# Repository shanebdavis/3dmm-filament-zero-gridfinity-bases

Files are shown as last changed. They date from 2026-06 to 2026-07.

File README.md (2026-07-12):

# 3DMM Filament Zero — Gridfinity Bases

**What is the absolute minimum filament — and print time — that still makes a usable
Gridfinity base?** That's the whole point of this project. At this point the answer is,
in truth, *filament approximately zero*: there's no way to remove any more material
without making the base non-functional. Hence the name.

Part of the **3D Modular Madness** collection. Released on MakerWorld:
https://makerworld.com/en/models/1384108-gridfinity-base-fastest-lightest-customizable

## The variants

Three levels of structure, depending on your needs — plus connectable versions of each:

- **Net+** — Doubly flexible, but strong in *tension* — which is mostly what a Gridfinity
  base needs anyway. By far the lightest and fastest print. (`net_light` in the source.)
- **Tape+** — Adds horizontal sliding rigidity while staying flexible. Probably the sweet
  spot if you don't care about looks. (`net_heavy` in the source.)
- **Beam** — If you want it to look nice *and* want the strongest option, go for the beam:
  a traditional-looking solid Gridfinity base, still trimmed to the bone for speed.
  (`rigid` in the source.)
- **Beam+** — Beam, made connectable (see below). Identical to Beam except the *exposed*
  outer-perimeter corners use a special profile designed to mate with neighbouring prints.
  Any perimeter corner on an edge with a drawer spacer falls back to the plain Beam outer
  corner. (`net_rigid` in the source.)

### Connecting plates into one big grid

A natural fallout of how the Net and Tape versions are built: their corners made it
natural to design a **connector** that joins separately-printed plates, so if possible you
can interconnect all your Gridfinity into one large piece. Once the connectors existed,
**Beam+** followed — so the nicest-looking, strongest option can use the connectors too.

## Benchmarks

Bambu Studio slicer estimates on an **A1 mini**, normalized per 42 mm tile (most rows are a
4×4 / 16-tile plate). Lower is better on both columns. ★ = this project.

| Model | By | g / tile | s / tile |
|---|-----|---:|---:|
| ★ **3DMM Net+** | this project | **0.167** | **23.5** |
| Ultralight+ Gridfinity Bases | DBT85 | 0.267 | 52.3 |
| ★ **3DMM Tape+** | this project | 0.326 | 49.9 |
| ★ **3DMM Beam** | this project | 0.500 | 74.4 |
| Lightest Gridfinity Base Ever | Sparky | 0.780 | 96.3 |
| 3DMM Original Ultimate Turbo | this project (old) | 0.828 | 51.9 |
| Gridfinity Lightweight Stackable | DJR Engineering | 1.081 | 123.8 |
| Slim Gridfinity Base (IKEA Alex) | — | 1.258 | 138.9 |
| Gridfinity Simple Base | Schmidsfeld | 1.324 | 243.8 |

Highlights:

- **Net+ is the lightest and fastest base in the field** — 0.167 g/tile, ~37% less filament
  than the next-lightest (Ultralight+) and ~2.2× faster per tile.
- **Beam — a traditional, solid-looking base — beats "Lightest Gridfinity Base Ever"** by
  ~36% on filament and ~23% on time, while still looking like a normal Gridfinity base.
- **Tape+** adds real semi-rigid cross-bracing for only a little more filament than corner-only
  designs, at comparable print speed (49.9 s/tile vs Ultralight+'s 52.3 s/tile).
- Versus a standard Simple Base, **Net+ uses ~1/8th the filament and prints ~10× faster** per tile.

## Repo layout

```
src/               OpenSCAD source — the parametric assembler
stl/               Source geometry: per-variant Corner and Connector STLs
tools/             STL → polyhedron() inliner (regenerates the geometry baked into the .scad)
inline-stls.sh     Convenience wrapper: re-inline the STLs into the .scad
generate.sh        Batch-render the standard sizes for every model type
export_plates.sh   Auto Baseplates: render each plate to its own STL (build/plates/)
make_makerworld.sh Generate the two MakerWorld customizer variants (build-src/)
tools/build_variants.py  The variant builder behind make_makerworld.sh
build-src/         The generated customizer variants, committed so the shipped
                   files exist verbatim even without rerunning the generator
```

`src/gridfinity_base.scad` is **self-contained**: the corner / connector geometry is
inlined directly as `polyhedron()` blocks, so the single file renders anywhere —
including MakerWorld's Parametric Model Maker — with no external STL dependencies. The
`stl/` folder is kept as the editable source of truth, and `tools/inline_stls.py`
regenerates the inlined blocks from it. See *Inlining the geometry* below.

## Installing OpenSCAD

On macOS, install via Homebrew:

```
brew install --cask openscad
```

This installs the OpenSCAD app (and the `openscad` CLI used for headless rendering).

## Customizing your layout (OpenSCAD)

1. Open `src/gridfinity_base.scad` in OpenSCAD.
2. Open the Customizer: **Window → Customizer**.
3. Set:
   - **Model** — Net+, Tape+, Beam+, or Beam
   - **Sparse** — merge cells up to double width/depth and drop the internal walls
     between them: roughly **half the filament and print time** on large areas.
     Corners stay at standard Gridfinity positions (nothing is scaled — only the
     connectors between corners stretch), so bins seat and plates tile exactly as
     usual, just with less support under them. Works per plate in Auto Baseplates
     too; half cells are never merged, and it's ignored when Custom Shape cuts
     are set.
   - **Columns** / **Rows** — grid size in 42 mm cells, in 0.5 steps from 1 to 20.5.
     A `.5` appends a fully-enclosed half-cell (21 mm) column and/or row, for fitting
     odd drawer sizes (e.g. `2.5` = two full cells plus a half)
   - **Custom Shape** — carve a non-rectangular plate by removing squares from the
     left / right end of each row (row 1 = the front row). Corners, connectors and
     drawer spacers all adapt automatically: spacers only run along squares that
     survived the cuts, and each row always keeps at least one square. The Console
     warns if adjacent rows no longer overlap (which would split the plate in two).
   - **Drawer Spacers** — front / back / left / right, in mm (0 = none, 41 mm max).
     Adds a triangular spacer that projects outward from that edge so the plate sits
     flush in a drawer. Each is independent, so you can pad just the sides you need.
     A tie-rail runs along the outer edge of each spaced side, locking the spacers
     together for rigidity. Past 41 mm, add another Gridfinity cell instead.
   - **Auto Baseplates** — fill a whole area with one click: enter the total width
     and depth to cover (both must be non-zero to activate — otherwise everything
     works as normal) and pick your printer (or a custom printable area). Printer
     sizes are the largest single-color rectangle from the official Bambu Studio
     machine profiles, not the advertised bed — e.g. the P1/X1 series lose an
     18×28 mm front-left corner to the filament-cutter stopper (so 238×256 usable,
     with plates placed right of the corner), and the dual-nozzle H2D/H2C print a
     single color from one nozzle, which only reaches 325 mm of the bed. The solver
     fits the largest half-cell grid inside the area, splits it into plates that each
     fit your printer, and converts the leftover millimeters into drawer spacers so
     the assembled footprint is *exactly* what you entered. While active it overrides
     Grid, Drawer Spacers and Custom Shape. **Width alignment** (left / center /
     right / none) and **Depth alignment** (front / center / back / none) pick which
     side of the drawer the grid hugs — the spacers fill the opposite side(s), and
     "none" drops them so the set shrinks to the bare grid on that axis. **Half
     tiles** (uncheck for whole 42 mm squares only; the extra leftover goes to the
     spacers). The preview shows all plates laid out in their assembled
     positions with a small gap. With **Beam+**, plate-to-plate edges get the
     interlocking corners automatically, so the finished grid clips together.
     The Console lists every plate size and its printed footprint.

     To print, export the whole layout as **one STL**, import it into the slicer,
     then **Split to Objects** and auto-arrange (press **A** in Bambu Studio) —
     every plate separates cleanly into its own object (see *cavity vents* in the
     MakerWorld section). To render each plate to its own file instead, run

     ```
     ./export_plates.sh -D cover_width=500 -D cover_depth=450 -D 'printer="p1s"'
     ```

     which renders every plate in parallel to `build/plates/… - Plate NN.stl`
     (driving the hidden `export_plate` parameter via `-D`). Plates are numbered
     left to right, then front to back.
   - **Advanced** — pitch (42 mm = standard Gridfinity), centering, and preview colour
4. `F5` to preview, `F6` to render, then **File → Export → Export as STL**.

The **Console** (**View → Console**) prints the total outer footprint in mm
(`Total size: … wide (X) x … deep (Y)`), including any spacers, so you can check it
against your drawer before exporting.

## Publishing on MakerWorld (two customizers)

MakerWorld gets **two purpose-built customizer scripts**, both generated from
the one source file:

```
./make_makerworld.sh
# -> build-src/3DMM Filament Zero Gridfinity Single Baseplate.scad   (Single-Plate)
# -> build-src/3DMM Filament Zero Gridfinity Multi Baseplate.scad    (Multi-Plate)
```

MakerWorld auto-expands only the *first* parameter group, so each variant leads
with a **Basic** group holding everything a user normally touches:

- **Single-Plate**: Basic (model, grid size, sparse, drawer spacers), then
  Custom Shape and Advanced — the classic one-plate customizer, with the Auto
  Baseplates solver pinned off.
- **Multi-Plate**: Basic (model, printer, area to cover, fill toggles, sparse),
  then Advanced. The manual Grid / Drawer Spacers / Custom Shape settings are
  pinned off, and it ships with a 400×400 mm cover area so the first preview
  shows a real layout.

Both are plain single-output scripts — deliberately **no Parametric Model
Maker multi-plate hooks** — so MakerWorld keeps the **STL download** button on
both listings. STL is the point: PMM's multi-plate 3MF ships MakerWorld's
default print profile, which is wrong for these models, and walking makers
through exporting objects out of it into a correct profile was tedious. With
an STL the maker starts inside our published print profile and stays there.
Printing a Baseplate Set is three inputs in Bambu Studio: import the STL into
the print profile, click it and **Split to Objects**, press **A** to
auto-arrange. Done.

Each variant is the source file with only the Customizer parameter header
rearranged — parameters of omitted sections are pinned to their defaults in a
hidden block, and everything below the header is emitted byte-identical.
`tools/build_variants.py` fails the build if an expected section or parameter
disappears, so the variants can't silently drift from
`src/gridfinity_base.scad` (which remains the full-capability script for local
development). MakerWorld names the downloaded file after the uploaded `.scad`,
so the build outputs carry the product names — rename them in
`tools/build_variants.py` if the product names change.

### Cavity vents (why Split to Objects works)

The Beam/Beam+ corners intentionally enclose sealed air pockets at interior
cell crossings — they split the doubled walls into separated perimeter lines
when sliced. A sealed cavity is always a separate shell in an exported mesh,
so slicers' *Split to Objects* used to break those pockets out as dozens of
loose boxes (and silently delete the inner structure from the plate). Every
pocket is therefore vented to the plate's underside through a hair-thin
channel (`crossing_vents()` in the source): the mesh becomes one connected
shell per plate, the pockets survive splitting, and the channels are far below
one extrusion width so they never appear in toolpaths.

## References & inspiration

These makers did excellent work, and their designs directly inspired this project. They
raised the bar — this project is my attempt to push it further. Go give them a boost.

- **[Ultralight+ Gridfinity Bases](https://makerworld.com/en/models/1226917-ultralight-gridfinity-bases)**
  by DBT85 — Corner-only alignment bases (the grid sides are skipped entirely, since only
  the corners are needed to align bins), with optional pins to connect plates. Roughly
  6.5 g and ~20 min for a 2-wall 5×5 on a P1S. The closest reference point for the
  **Net+** and **Tape+** variants.
- **[Lightest Gridfinity Base Ever – Customizable](https://makerworld.com/en/models/1685835-lightest-gridfinity-base-ever-customizable)**
  by Sparky — Parametric, skeletonized walls-only base with the bottom lip and inter-grid
  overhangs removed; a 4×4 in ~14 min on a 0.8 mm nozzle (1 wall). The reference point for
  the **Beam** variant.
- **[Gridfinity Lightweight Stackable Base Plates](https://makerworld.com/en/models/1927235-gridfinity-lightweight-stackable-base-plates)**
  by DJR Engineering — A clever stackable "peanut" interlock so you can run a whole
  Z-height stack overnight. It requires support material (an AMS) to separate the stacked
  layers. A genuinely interesting idea — but in practice the support material and per-plate
  overhead mean it isn't a net win on time or filament versus printing flat.
- **[Gridfinity Simple Base – all sizes](https://makerworld.com/en/models/700948-gridfinity-simple-base-all-sizes)**
  by Schmidsfeld — The popular, standard full baseplate (built with the FreeCAD Gridfinity
  Workbench). The non-optimized baseline for "normal" Gridfinity weight and print time.

Gridfinity itself was created by Zack Freeman as an open, free system — a framework for the
community.

## How it works

The base is assembled from two reused source parts per variant — a **corner** and a
**connector** beam. `src/gridfinity_base.scad` places four corners per 42 mm cell and
joins them with connector beams, then tiles that cell across your chosen grid. Because
every cell reuses the same inlined geometry, file size and slicing stay tiny even on
large plates.

## Inlining the geometry (and the STL winding gotcha)

The corner and connector parts are modeled by hand (in Shapr3D) and live in `stl/` as
small binary STL meshes. Rather than have the `.scad` `import()` them at render time —
which needs the files alongside the script and is **not supported by MakerWorld's
Parametric Model Maker** — the geometry is **inlined** into `src/gridfinity_base.scad`
as `polyhedron()` blocks. That makes the script a single self-contained file that runs
anywhere.

The mapping lives in the source itself: each inlined module is preceded by a directive
comment naming its STL, e.g.

```
// source-stl: AT Net Rigid Outer Corner.stl (normalize)
module mesh_corner_net_rigid_outer() {
  polyhedron( ... );
}
```

Running `./inline-stls.sh` (a thin wrapper around `tools/inline_stls.py`) scans those
directives, reads each named STL from `stl/`, converts it, and rewrites that module in
place — so after editing a mesh you just re-export the STL and run the script. It can be
run from anywhere; `(normalize)` shifts a corner mesh so its outer corner lands at the
origin.

For a tight edit loop, run `./inline-stls.sh --watch`: it stays running and re-inlines
automatically whenever any `stl/*.stl` changes, so re-exporting from your modeller is
enough to refresh the `.scad` (it only rewrites the file when the geometry actually
changes). Ctrl-C to stop.

Per mesh, the conversion (binary STL → `polyhedron()`) is:

1. **Parse** the binary STL triangles.
2. **Weld** duplicate vertices (round to 4 dp, dedupe) into a points + faces list, so the
   result is a clean manifold rather than triangle soup.
3. **Normalize** corner meshes so the outer corner sits at the origin in the +X +Y
   quadrant (the script then just rotates and places them).
4. **Reverse the face winding** — see below.
5. Emit `polyhedron(points=…, faces=…, convexity=6)`.

### The winding gotcha

STL and OpenSCAD disagree on how a triangle's vertices are ordered:

- **STL** orders them **counter-clockwise as seen from outside** (the outward normal by
  the right-hand rule).
- **OpenSCAD `polyhedron()`** wants them **clockwise from outside**.

So copying STL triangles straight into `polyhedron()` produces **inverted, inside-out
normals**. This is easy to miss because it depends on the rendering backend:

- **CGAL** (older OpenSCAD, e.g. the 2021 macOS build) re-orients faces by topology, so it
  silently fixes the inversion — everything looks fine locally.
- **Manifold** (newer OpenSCAD, and what **MakerWorld** uses) trusts the supplied winding,
  so the inverted faces render inside-out.

That's exactly the bug we hit: the corners and the beam connector (both `polyhedron()`)
showed inside-out on MakerWorld while the native `cube()` connectors were fine, and the
local Mac app looked correct either way. The fix is to **reverse every face**
(`[a,b,c] → [a,c,b]`) during conversion. `tools/inline_stls.py` does this robustly: it
computes each mesh's signed volume and flips the winding whenever the source comes in
counter-clockwise, so the result is correct regardless of how the STL was exported.

## License

MIT — see [LICENSE](LICENSE).

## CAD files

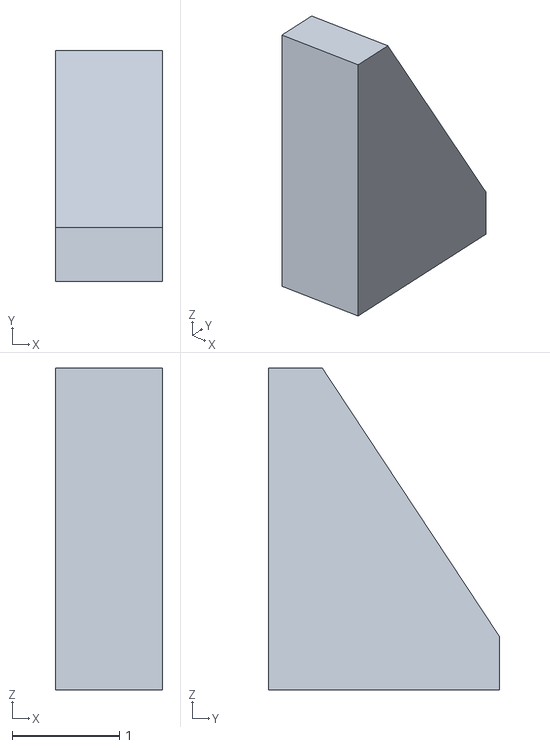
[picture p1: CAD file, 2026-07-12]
stl/AT Extension V2 End.stl
1.00 x 2.15 x 3.00

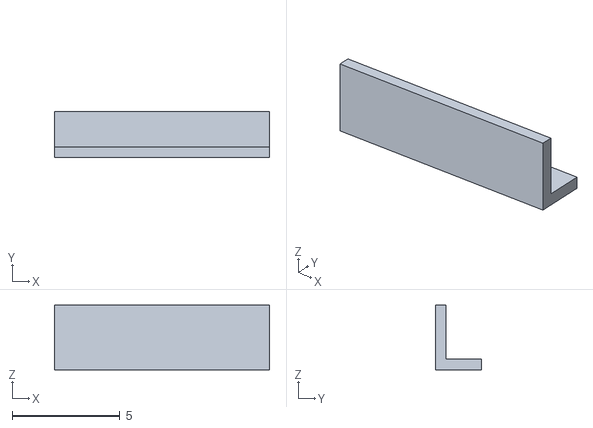
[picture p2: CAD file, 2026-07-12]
stl/AT Extension V2 Extender.stl
10.0 x 2.15 x 3.00

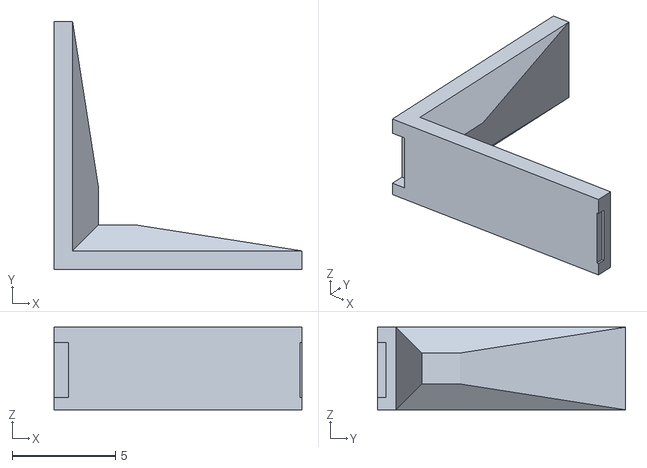
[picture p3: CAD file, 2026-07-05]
stl/AT Rigid Inner Corner.stl
12.0 x 12.0 x 4.00

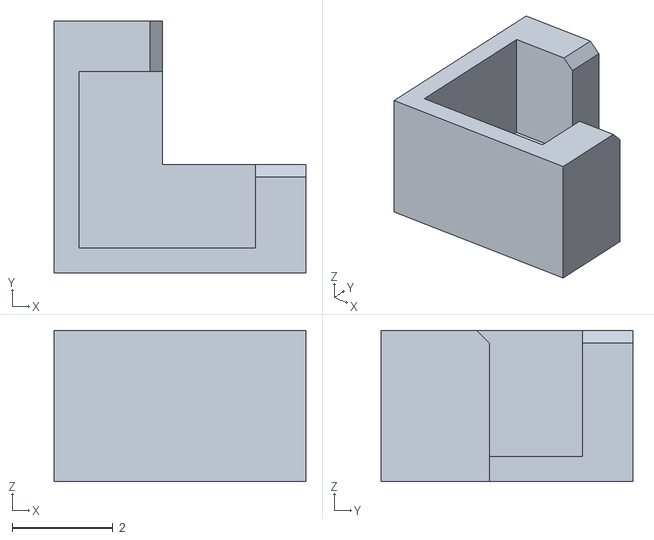
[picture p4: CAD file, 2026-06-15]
stl/AT Net Heavy Corner.stl
5.00 x 5.00 x 3.00

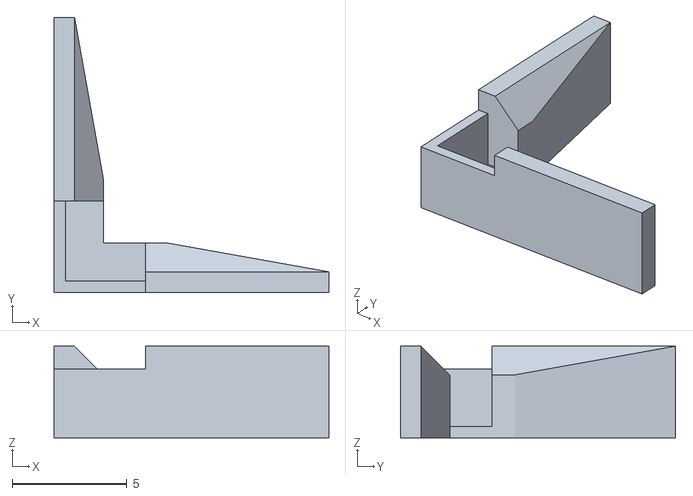
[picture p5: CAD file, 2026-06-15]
stl/AT Net Rigid InnerOuter Corner.stl
12.0 x 12.0 x 4.00

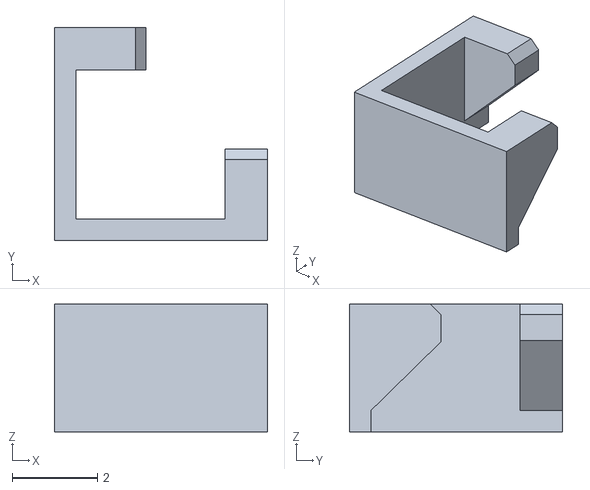
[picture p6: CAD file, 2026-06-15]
stl/AT Net Light Corner.stl
5.00 x 5.00 x 3.00

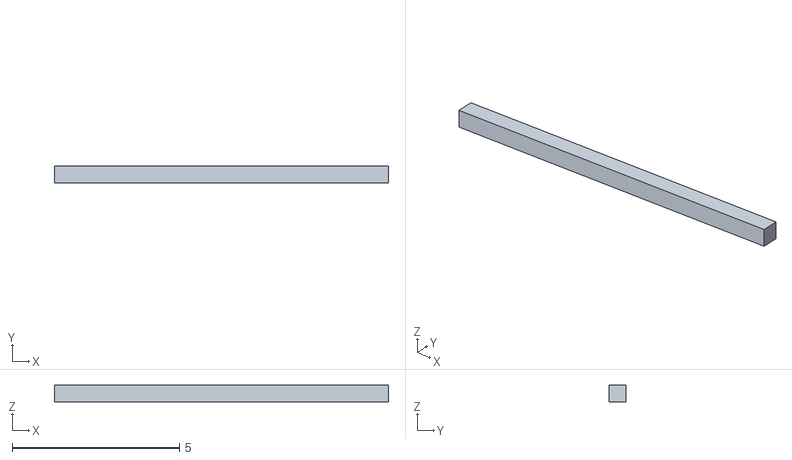
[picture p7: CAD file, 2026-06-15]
stl/AT Net Light Connector.stl
10.0 x 0.5 x 0.5

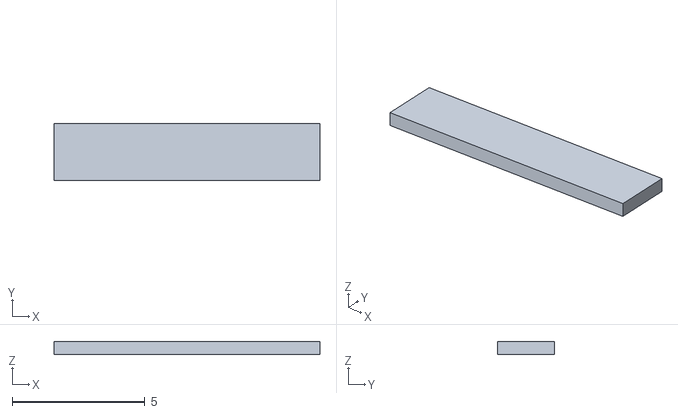
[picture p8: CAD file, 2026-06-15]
stl/AT Net Heavy Connector.stl
10.0 x 2.15 x 0.5

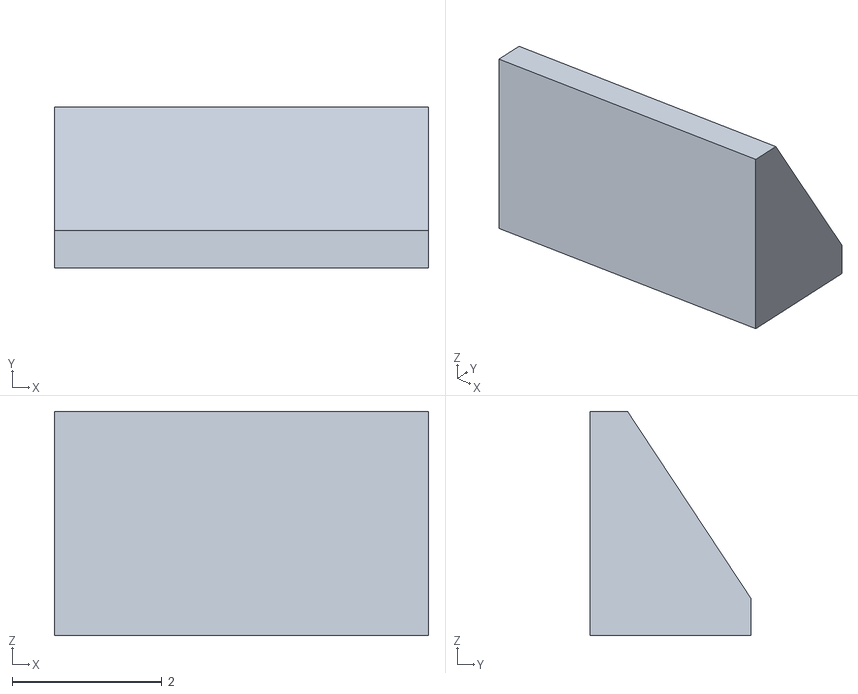
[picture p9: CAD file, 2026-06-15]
stl/AT Extension.stl
5.00 x 2.15 x 3.00

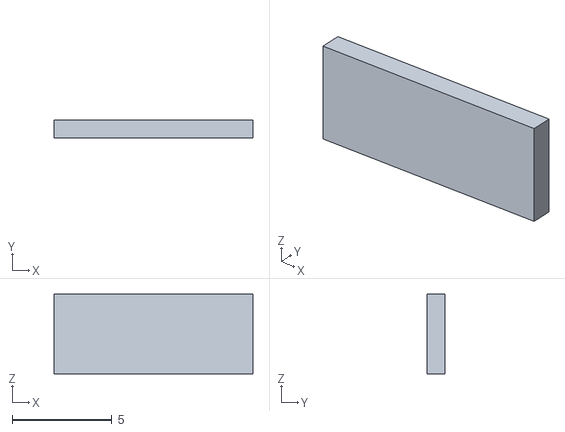
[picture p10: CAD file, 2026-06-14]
stl/AT Net Rigid Connector.stl
10.0 x 0.9 x 4.00

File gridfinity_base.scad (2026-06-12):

// ============================================================
//  AT Ultra-Light Gridfinity Base  —  parametric assembler
// ============================================================
//  Keep this .scad file in the SAME folder as the corner STLs,
//  because import() uses relative paths.
//
//  Open in OpenSCAD, then: Window menu -> Customizer to get the
//  dropdown + sliders below. F5 = preview, F6 = render, then
//  File -> Export -> Export as STL.
// ============================================================

/* [Model] */
// Which base style to build
model = "net_light"; // [net_light:Net Light, net_heavy:Net Heavy, rigid:Solid (Rigid)]

/* [Grid] */
// Squares wide
columns = 2; // [1:1:20]
// Squares tall
rows = 2;    // [1:1:20]

/* [Advanced] */
// Grid spacing in mm (42 = standard gridfinity)
pitch = 42;      // [21:1:84]
// Smoothness of any curves
$fn = 48;

// ---- end of Customizer parameters --------------------------

// Per-model lookup. The "offset" is where each STL currently sits
// in space (Shapr3D laid them out side by side); we subtract it so
// every corner's OUTER corner lands at the origin (0,0).
corner_file =
    model == "net_light" ? "AT Net Light Corner.stl" :
    model == "net_heavy" ? "AT Net Heavy Corner.stl" :
                           "AT Rigid Corner.stl";

corner_offset =
    model == "net_light" ? [250, 200, 0] :
    model == "net_heavy" ? [300, 200, 0] :
                           [350, 200, 0];

// Corner footprint along an edge (mm)
corner_size = (model == "rigid") ? 12 : 5;

// Connector cross-section: width (across the edge) x height (up)
conn_w = model == "net_light" ? 0.5 :
         model == "net_heavy" ? 2.15 :
                                0.9;   // rigid
conn_h = (model == "rigid") ? 4.0 : 0.5;

// ------------------------------------------------------------
// One imported corner, normalized so its outer corner is at origin
// and it occupies the +X +Y quadrant (profile faces toward center).
module corner_part() {
    translate([-corner_offset[0], -corner_offset[1], -corner_offset[2]])
        import(corner_file);
}

// A connector beam running along +X, flush to the outer edge
// (y: 0..conn_w) and sitting on the bed (z: 0..conn_h).
module connector(len) {
    cube([len, conn_w, conn_h]);
}

// One 42mm (pitch) cell: 4 corners + 4 edge connectors.
// We place the bottom-left corner and its bottom-edge connector,
// then rotate that whole pair 0/90/180/270 about the cell center
// to fill the other three corners and edges.
module cell() {
    gap = pitch - 2 * corner_size;   // length of each connector
    for (a = [0, 90, 180, 270])
        translate([pitch/2, pitch/2, 0])
            rotate([0, 0, a])
                translate([-pitch/2, -pitch/2, 0]) {
                    corner_part();
                    // Butt-joined exactly against the corners — no overlap,
                    // geometry untouched. Coincident faces union cleanly.
                    translate([corner_size, 0, 0])
                        connector(gap);
                }
}

// Tile the cell across the requested grid.
module grid() {
    for (i = [0 : columns - 1], j = [0 : rows - 1])
        translate([i * pitch, j * pitch, 0])
            cell();
}

grid();

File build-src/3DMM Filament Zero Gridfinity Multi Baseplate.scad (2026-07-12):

// ============================================================
//  GENERATED FILE - do not edit. Built by tools/build_variants.py
//  (./make_makerworld.sh) from src/gridfinity_base.scad.
//  Variant: Multi-Plate customizer
// ============================================================

// ============================================================
//  AT Ultra-Light Gridfinity Base  —  parametric assembler
// ============================================================
//  Self-contained: all geometry is inlined as polyhedron() below, so
//  this single file runs anywhere (incl. MakerWorld's Parametric Model
//  Maker / customizer) with no external STL dependencies.
//
//  Open in OpenSCAD, then: Window menu -> Customizer to get the
//  dropdown + sliders below. F5 = preview, F6 = render, then
//  File -> Export -> Export as STL.
// ============================================================

/* [Basic] */
// Which base style to build
model = "net_rigid"; // [net_light:Net+, net_heavy:Tape+, rigid:Beam, net_rigid:Beam+]

// Cover a whole area (a drawer, a shelf) with auto-sized plates: pick your printer,
// set BOTH cover sizes non-zero, and the solver fills the area with the largest grid
// that fits, splits it into plates sized for your printer, and turns the leftover
// millimeters into edge spacers so the assembled footprint is exactly what you asked
// for. While active, the manual Grid, Drawer Spacers and Custom Shape settings are
// ignored.
// Printer the plates must fit on. Sizes are the largest single-color rectangle from the
// official Bambu Studio machine profiles, not the advertised bed: P1/X1 series lose an
// 18x28mm front-left corner to the filament-cutter stopper (plates print full-depth,
// nudged right of the corner), and the dual-nozzle H2/X2 machines are limited to one
// nozzle's reach for a single color.
printer = "p1s"; // [a1_mini:A1 mini (180x180), a1:A1 / P2S / X2D (256x256), p1s:P1P / P1S / X1C / X1E (238x256 - cutter corner), a2l:A2L (330x320), h2s:H2S (340x320), h2d:H2D / H2D Pro / H2C (325x320 single color), custom:Custom (set size under Advanced)]
// Total width (mm) of the area to cover. 0 = off.
cover_width = 400; // [0:1:2000]
// Total depth (front-to-back, mm) of the area to cover. 0 = off.
cover_depth = 400; // [0:1:2000]
// Where the grid sits inside the covered width: drawer spacers fill the leftover millimeters on the other side(s), so the assembled footprint is exactly the cover width. None = no width spacers (the set shrinks to the grid).
width_align = "center"; // [left:Left, center:Center, right:Right, none:None]
// Where the grid sits inside the covered depth. None = no depth spacers.
depth_align = "front"; // [front:Front, center:Center, back:Back, none:None]
// Use a trailing half-size (21mm) column/row when it fits the cover size better. Uncheck for whole 42mm squares only - the leftover goes to the drawer spacers instead.
half_tiles = false;

// Sparse: halves your filament cost by removing internal geometry, while staying fully Gridfinity compatible. Ideal for larger layouts with larger trays.
sparse = false;

/* [Advanced] */
// Center on the plate
centered = true;
// Grid spacing in mm (42: standard gridfinity, 84: double, 168: quad)
pitch = 42;      // [21:1:168]

// Auto Baseplates only: gap between plates in the preview/export, so the slicer's Split to Objects cleanly separates them
tile_gap = 5; // [2:0.5:20]

// Auto Baseplates, Printer = Custom only: printable width (mm)
custom_print_width = 256; // [100:1:1000]
// Auto Baseplates, Printer = Custom only: printable depth (mm)
custom_print_depth = 256; // [100:1:1000]

// Customize the preview color to match your filament. Use standard HTML color codes: e.g. #ff0000 for red. This does not affect the model output.
preview_color = "#0099ff";

/* [Hidden] */
// Fixed in this variant - not part of this customizer's UI.
columns = 4; // [1:0.5:10]
rows = 4;    // [1:0.5:10]
spacer_front = 0; // [0:0.5:41]
spacer_left  = 0; // [0:0.5:41]
spacer_back  = 0; // [0:0.5:41]
spacer_right = 0; // [0:0.5:41]
row_1_left = 0; // [0:1:9]
row_1_right = 0; // [0:1:9]
row_2_left = 0; // [0:1:9]
row_2_right = 0; // [0:1:9]
row_3_left = 0; // [0:1:9]
row_3_right = 0; // [0:1:9]
row_4_left = 0; // [0:1:9]
row_4_right = 0; // [0:1:9]
row_5_left = 0; // [0:1:9]
row_5_right = 0; // [0:1:9]
row_6_left = 0; // [0:1:9]
row_6_right = 0; // [0:1:9]
row_7_left = 0; // [0:1:9]
row_7_right = 0; // [0:1:9]
row_8_left = 0; // [0:1:9]
row_8_right = 0; // [0:1:9]
row_9_left = 0; // [0:1:9]
row_9_right = 0; // [0:1:9]
row_10_left = 0; // [0:1:9]
row_10_right = 0; // [0:1:9]

// ---- end of Customizer parameters --------------------------
// Everything below is internal. The [Hidden] group keeps these
// constants (beam_len, ext_base_len, rail_*, etc.) out of the
// OpenSCAD / MakerWorld Customizer UI.
/* [Hidden] */

// Auto Baseplates only: render a single plate by number (1 = front-left plate,
// counting left to right then front to back) instead of the whole layout. A
// scripting hook for export_plates.sh (openscad -D export_plate=N); 0 = the
// whole layout.
export_plate = 0; // [0:1:36]

// Corner footprint along an edge (mm). Solid and Solid+ share the 12mm corner.
corner_size = (model == "rigid" || model == "net_rigid") ? 12 : 5;

// Connector cross-section: width (across the edge) x height (up). Solid+ (net_rigid)
// uses the same 0.9 x 4.0 connector as Solid (rigid) — it looks just like Solid; only
// its outer-perimeter corners differ (see corner_part).
conn_w = model == "net_light" ? 0.5 :
         model == "net_heavy" ? 2.15 :
                                0.9;   // rigid + net_rigid
conn_h = (model == "rigid" || model == "net_rigid") ? 4.0 : 0.5;

// ------------------------------------------------------------
// One corner, already normalized (outer corner at the origin, in the +X +Y quadrant
// with the profile facing the cell centre). Solid (rigid) and Solid+ (net_rigid)
// distinguish corner roles by how many of the corner's two edges lie on the plate
// boundary:
//   both edges on boundary  -> `outer` corner (a true plate corner)
//   one edge on boundary    -> `innerouter` corner (sits mid-edge: one side is the
//                              perimeter wall, the other mates with the neighbouring cell)
//   neither edge on boundary -> `inner` corner (fully interior, where four cells meet)
// `outer` is true whenever at least one edge is on the boundary; `both` narrows that to a
// true plate corner. Solid+ adds the `plus` role: where any on-boundary edge is *exposed*
// (no drawer spacer) it mates with a neighbouring print, so it swaps in the special Solid+
// outer/innerouter mesh. Only when every boundary edge at the corner is spacered (extenders
// run in each boundary direction) does it fall back to the plain Solid corner.
//
// The InnerOuter mesh is asymmetric — its outer (perimeter) edge runs along local +X and
// its inner (mating) edge along local +Y. rcell places every corner so local +X points at
// that corner's "canonical" boundary side; when the actual boundary edge is the *other*
// one, `swap` mirrors the mesh across its diagonal (swap X/Y) to put the perimeter wall on
// the right edge. `open` marks a corner whose two adjacent squares are present but whose
// diagonal square was removed by a Custom Shape cut (a re-entrant plate corner). Solid+
// must NOT use the fully-interior corner there: its edge-connector clip only fits an
// intersection where every square-corner presents the connectable outer profile, so any
// missing square at the intersection forces the outer piece on all corners around it.
// Plain Solid has no clip and keeps the interior corner. `plus`/`outer`/`both`/`swap`/
// `open` are supplied by rcell; the flexible-net models ignore them all.
module corner_part(plus = true, outer = true, both = true, swap = false, open = false) {
    if      (model == "net_light")                        mesh_corner_net_light();
    else if (model == "net_heavy" || model == "net_beam") mesh_corner_net_heavy();
    else if (model == "net_rigid") {
        if      (plus && both)  mesh_corner_net_rigid_outer();
        else if (plus)          diag(swap) mesh_corner_net_rigid_innerouter();
        else if (outer && both) mesh_corner_rigid_outer();
        else if (outer)         diag(swap) mesh_corner_rigid_innerouter();
        else if (open)          mesh_corner_net_rigid_outer();
        else                    mesh_corner_rigid_inner();
    }
    else {  // rigid / Solid
        if      (outer && both) mesh_corner_rigid_outer();
        else if (outer)         diag(swap) mesh_corner_rigid_innerouter();
        else                    mesh_corner_rigid_inner();
    }
}
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

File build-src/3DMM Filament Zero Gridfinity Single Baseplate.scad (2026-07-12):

// ============================================================
//  GENERATED FILE - do not edit. Built by tools/build_variants.py
//  (./make_makerworld.sh) from src/gridfinity_base.scad.
//  Variant: Single-Plate customizer
// ============================================================

// ============================================================
//  AT Ultra-Light Gridfinity Base  —  parametric assembler
// ============================================================
//  Self-contained: all geometry is inlined as polyhedron() below, so
//  this single file runs anywhere (incl. MakerWorld's Parametric Model
//  Maker / customizer) with no external STL dependencies.
//
//  Open in OpenSCAD, then: Window menu -> Customizer to get the
//  dropdown + sliders below. F5 = preview, F6 = render, then
//  File -> Export -> Export as STL.
// ============================================================

/* [Basic] */
// Which base style to build
model = "rigid"; // [net_light:Net+, net_heavy:Tape+, rigid:Beam, net_rigid:Beam+]

// Squares wide
columns = 4; // [1:0.5:10]
// Squares deep
rows = 4;    // [1:0.5:10]

// Sparse: halves your filament cost by removing internal geometry, while staying fully Gridfinity compatible. Ideal for larger layouts with larger trays.
sparse = false;

// Outward spacer on each side (mm) so the plate sits flush in a drawer. 0 = none.
// Capped at 41 mm — past that, just add another Gridfinity cell instead.
// Front Spacer (mm)
spacer_front = 0; // [0:0.5:41]
// Left Spacer (mm)
spacer_left  = 0; // [0:0.5:41]
// Back Spacer (mm)
spacer_back  = 0; // [0:0.5:41]
// Right Spacer (mm)
spacer_right = 0; // [0:0.5:41]

/* [Custom Shape] */
// Remove squares from row 1 left
row_1_left = 0; // [0:1:9]
// Remove squares from row 1 right
row_1_right = 0; // [0:1:9]
// Remove squares from row 2 left
row_2_left = 0; // [0:1:9]
// Remove squares from row 2 right
row_2_right = 0; // [0:1:9]
// Remove squares from row 3 left
row_3_left = 0; // [0:1:9]
// Remove squares from row 3 right
row_3_right = 0; // [0:1:9]
// Remove squares from row 4 left
row_4_left = 0; // [0:1:9]
// Remove squares from row 4 right
row_4_right = 0; // [0:1:9]
// Remove squares from row 5 left
row_5_left = 0; // [0:1:9]
// Remove squares from row 5 right
row_5_right = 0; // [0:1:9]
// Remove squares from row 6 left
row_6_left = 0; // [0:1:9]
// Remove squares from row 6 right
row_6_right = 0; // [0:1:9]
// Remove squares from row 7 left
row_7_left = 0; // [0:1:9]
// Remove squares from row 7 right
row_7_right = 0; // [0:1:9]
// Remove squares from row 8 left
row_8_left = 0; // [0:1:9]
// Remove squares from row 8 right
row_8_right = 0; // [0:1:9]
// Remove squares from row 9 left
row_9_left = 0; // [0:1:9]
// Remove squares from row 9 right
row_9_right = 0; // [0:1:9]
// Remove squares from row 10 left
row_10_left = 0; // [0:1:9]
// Remove squares from row 10 right
row_10_right = 0; // [0:1:9]

/* [Advanced] */
// Center on the plate
centered = true;
// Grid spacing in mm (42: standard gridfinity, 84: double, 168: quad)
pitch = 42;      // [21:1:168]
// Customize the preview color to match your filament. Use standard HTML color codes: e.g. #ff0000 for red. This does not affect the model output.
preview_color = "#0099ff";

/* [Hidden] */
// Fixed in this variant - not part of this customizer's UI.
printer = "p1s"; // [a1_mini:A1 mini (180x180), a1:A1 / P2S / X2D (256x256), p1s:P1P / P1S / X1C / X1E (238x256 - cutter corner), a2l:A2L (330x320), h2s:H2S (340x320), h2d:H2D / H2D Pro / H2C (325x320 single color), custom:Custom (set size under Advanced)]
cover_width = 0; // [0:1:2000]
cover_depth = 0; // [0:1:2000]
width_align = "center"; // [left:Left, center:Center, right:Right, none:None]
depth_align = "front"; // [front:Front, center:Center, back:Back, none:None]
half_tiles = true;
tile_gap = 5; // [2:0.5:20]
custom_print_width = 256; // [100:1:1000]
custom_print_depth = 256; // [100:1:1000]

// ---- end of Customizer parameters --------------------------
// Everything below is internal. The [Hidden] group keeps these
// constants (beam_len, ext_base_len, rail_*, etc.) out of the
// OpenSCAD / MakerWorld Customizer UI.
/* [Hidden] */

// Auto Baseplates only: render a single plate by number (1 = front-left plate,
// counting left to right then front to back) instead of the whole layout. A
// scripting hook for export_plates.sh (openscad -D export_plate=N); 0 = the
// whole layout.
export_plate = 0; // [0:1:36]

// Corner footprint along an edge (mm). Solid and Solid+ share the 12mm corner.
corner_size = (model == "rigid" || model == "net_rigid") ? 12 : 5;

// Connector cross-section: width (across the edge) x height (up). Solid+ (net_rigid)
// uses the same 0.9 x 4.0 connector as Solid (rigid) — it looks just like Solid; only
// its outer-perimeter corners differ (see corner_part).
conn_w = model == "net_light" ? 0.5 :
         model == "net_heavy" ? 2.15 :
                                0.9;   // rigid + net_rigid
conn_h = (model == "rigid" || model == "net_rigid") ? 4.0 : 0.5;

// ------------------------------------------------------------
// One corner, already normalized (outer corner at the origin, in the +X +Y quadrant
// with the profile facing the cell centre). Solid (rigid) and Solid+ (net_rigid)
// distinguish corner roles by how many of the corner's two edges lie on the plate
// boundary:
//   both edges on boundary  -> `outer` corner (a true plate corner)
//   one edge on boundary    -> `innerouter` corner (sits mid-edge: one side is the
//                              perimeter wall, the other mates with the neighbouring cell)
//   neither edge on boundary -> `inner` corner (fully interior, where four cells meet)
// `outer` is true whenever at least one edge is on the boundary; `both` narrows that to a
// true plate corner. Solid+ adds the `plus` role: where any on-boundary edge is *exposed*
// (no drawer spacer) it mates with a neighbouring print, so it swaps in the special Solid+
// outer/innerouter mesh. Only when every boundary edge at the corner is spacered (extenders
// run in each boundary direction) does it fall back to the plain Solid corner.
//
// The InnerOuter mesh is asymmetric — its outer (perimeter) edge runs along local +X and
// its inner (mating) edge along local +Y. rcell places every corner so local +X points at
// that corner's "canonical" boundary side; when the actual boundary edge is the *other*
// one, `swap` mirrors the mesh across its diagonal (swap X/Y) to put the perimeter wall on
// the right edge. `open` marks a corner whose two adjacent squares are present but whose
// diagonal square was removed by a Custom Shape cut (a re-entrant plate corner). Solid+
// must NOT use the fully-interior corner there: its edge-connector clip only fits an
// intersection where every square-corner presents the connectable outer profile, so any
// missing square at the intersection forces the outer piece on all corners around it.
// Plain Solid has no clip and keeps the interior corner. `plus`/`outer`/`both`/`swap`/
// `open` are supplied by rcell; the flexible-net models ignore them all.
module corner_part(plus = true, outer = true, both = true, swap = false, open = false) {
    if      (model == "net_light")                        mesh_corner_net_light();
    else if (model == "net_heavy" || model == "net_beam") mesh_corner_net_heavy();
    else if (model == "net_rigid") {
        if      (plus && both)  mesh_corner_net_rigid_outer();
        else if (plus)          diag(swap) mesh_corner_net_rigid_innerouter();
        else if (outer && both) mesh_corner_rigid_outer();
        else if (outer)         diag(swap) mesh_corner_rigid_innerouter();
        else if (open)          mesh_corner_net_rigid_outer();
        else                    mesh_corner_rigid_inner();
    }
    else {  // rigid / Solid
        if      (outer && both) mesh_corner_rigid_outer();
        else if (outer)         diag(swap) mesh_corner_rigid_innerouter();
        else                    mesh_corner_rigid_inner();
    }
}

// Mirror children across the corner's diagonal (swap X/Y) when `s` is set — used to flip an
// asymmetric InnerOuter corner so its perimeter wall lands on the correct edge.
module diag(s) {
    if (s) multmatrix([[0,1,0,0],[1,0,0,0],[0,0,1,0],[0,0,0,1]]) children();
    else   children();
}
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

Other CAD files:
stl/AT Net Heavy Beam Connector.stl
stl/AT Rigid InnerOuter Corner.stl
stl/AT Rigid Connector.stl
src/gridfinity_base.scad

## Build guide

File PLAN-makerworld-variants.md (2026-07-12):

# Plan: Split MakerWorld Customizers (Single-Plate / Multi-Plate / Dev)

## The actual problem we're solving

MakerWorld's Parametric Model Maker (PMM) can export Auto Baseplates as a proper
multi-plate 3MF, but **we get almost no control over the print settings inside that
3MF**. This model needs heavily customized settings (ultra-light lattice), so the
downloaded 3MF has a bad print profile. Today the workaround is instructing the user
to open the downloaded 3MF, export every object out of it, and re-import them into a
properly configured print-profile 3MF — very tedious. The goal of every strategy below
is to reduce or eliminate that tedium.

Two strategies will be tried in parallel:

- **Strategy A** (this document, specified): restructure into purpose-built customizers
  so each MakerWorld listing is simple and the STL-friendly path stays first-class.
- **Strategy B** (TBD): to be specified next — a different attack on the print-profile
  problem itself.

## Current architecture (research summary)

- **`src/gridfinity_base.scad`** — single self-contained source of truth. Customizer
  sections in order: `[Model]`, `[Grid]`, `[Drawer Spacers]`, `[Custom Shape]`,
  `[Auto Baseplate Set Generation]`, `[Advanced]`, then `[Hidden]` internals, engine
  code, the Auto Baseplates solver, output modules (`assembly_view()`, `plate(k)`),
  a top-level render guarded by `if (!mw_export)`, and the inlined mesh modules.
- **`src/makerworld_hooks.scad`** — 36 `mw_plate_N()` modules + `mw_assembly_view()`.
  Must never coexist with a live top-level render (PMM renders the top level into
  every plate), which is why hooks live in a separate file.
- **`make_makerworld.sh`** — builds the current multi-plate upload variant:
  flips `mw_export = false` → `true` in the combined source, appends the hooks, writes
  `build/3DMM Filament Zero Gridfinity Baseplates.scad`.
- **`export_plates.sh`** — renders each auto plate to its own STL by passing
  `-D export_plate=k`. **Depends on the `export_plate` parameter existing.**
- **`generate.sh`** — batch STL renders of standard sizes from the combined source.
- **`inline-stls.sh` / `tools/inline_stls.py`** — regenerates the inlined
  `polyhedron()` modules inside `src/gridfinity_base.scad` (hardcoded path).
- OpenSCAD semantics that make this plan cheap: top-level variables are declarative
  (single assignment, position doesn't affect resolution), and everything after a
  `/* [Hidden] */` group header is excluded from the Customizer UI. So "removing" a
  parameter from a variant = moving its assignment into a hidden block; all engine
  code compiles unchanged.

## Strategy A: three build outputs from one source

### Source organization: keep the combined file (recommended)

Keep `src/gridfinity_base.scad` as the one source of truth, and add lightweight
**section markers** (comments like `// @section grid`) around the Customizer parameter
blocks. A new build tool assembles variants by transforming only the parameter header
(reorder sections, demote pinned params to a hidden block, flip `mw_export`) and
appending hooks where needed. The engine/solver/mesh code is byte-identical in every
variant.

Why not split into fragment files assembled by concatenation? It was considered
(`params_*.scad` + `core.scad` + `solver.scad` + per-target output files), but:

- The dev iteration cycle gets *worse*: you can no longer just open the src file in
  OpenSCAD and hit F5 — you'd have to rebuild after every edit or develop against a
  build artifact.
- `tools/inline_stls.py` and both shell scripts would need repointing.
- Cross-section references (e.g. `assembly_view()` touches manual *and* auto params)
  force either per-target code surgery or hidden-pin shims anyway — the same mechanism
  the header transform uses, with more moving parts.

With the combined file, **the dev "third output" is just `src/gridfinity_base.scad`
itself** — open it locally, full manual + auto capability, fastest possible iteration,
no MakerWorld anything (top level renders because `mw_export = false`). For symmetry
the build can still copy it to `build/` as the dev artifact, but nothing requires it.

### The three outputs

| Output | File (build/) | Audience |
|---|---|---|
| Single-Plate Customizer | `<single-name>.scad` | MakerWorld listing #1 |
| Multi-Plate Customizer | `<multi-name>.scad` | MakerWorld listing #2 |
| Dev / full combined | `src/gridfinity_base.scad` (optionally copied to build/) | local OpenSCAD |

MakerWorld names the downloaded file after the uploaded `.scad`, so the two build
filenames are product names — **naming decision needed** (e.g. "3DMM Filament Zero
Gridfinity Baseplate" vs "…Baseplate Set"; today's multi-plate name is
"3DMM Filament Zero Gridfinity Baseplates").

### Single-Plate Customizer

- Visible sections, in order: `[Model]`, `[Grid]`, `[Drawer Spacers]`,
  `[Custom Shape]`, `[Advanced]` (centered, pitch, preview color — **no
  `export_plate`**).
- Pinned hidden: `cover_width = 0`, `cover_depth = 0`, `printer`, custom print sizes,
  `tile_gap`, `mw_safe_plates`, `export_plate = 0`. Auto mode can never activate;
  the solver code is present but dead (harmless, small).
- No plate hooks, `mw_export` stays false → normal top-level render, so **MakerWorld
  keeps STL download enabled** — this is the easy on-ramp into a properly configured
  print-profile 3MF (import STL into our published profile).

### Multi-Plate Customizer

- Visible sections, in order: `[Model]`, then `[Auto Baseplate Set Generation]`
  promoted to slot 2 with **printer picker first, cover width/depth second** (basic
  operation: pick printer → pick area), then custom print sizes, `mw_safe_plates`;
  finally `[Advanced]` (centered, pitch, `tile_gap` moves here as a preview-only
  knob, preview color — no `export_plate`).
- Pinned hidden: `columns`, `rows`, all four `spacer_*`, all twenty `row_N_left/right`
  cut params, `export_plate = 0`.
- Built like today's variant: `mw_export = true` + hooks appended.
- **Decision needed — cover defaults**: with cover sizes defaulting to 0, auto mode is
  off and the variant renders a fallback 4×4 manual plate (current behavior). Options:
  (a) non-zero defaults (e.g. 400×400) so the first preview shows the real product,
  (b) keep 0 defaults + console note. Recommend (a).

### Build tool

Replace `make_makerworld.sh` with `tools/build_variants.py` (+ thin `build.sh`
wrapper, matching the repo's existing script style):

1. Parse `src/gridfinity_base.scad` into marked parameter sections + body.
2. For each variant: emit header (variant's section order), then a
   `/* [Hidden] */ // pinned by build` block for demoted params, then the unchanged
   body; flip `mw_export` and append `src/makerworld_hooks.scad` for the multi
   variant only.
3. Keep the existing sanity checks from `make_makerworld.sh` (marker present, hooks
   present, no `mw_` modules in src).
4. Fail loudly if a section marker or expected parameter is missing, so drift between
   the source and the build tool is caught immediately.

`export_plates.sh`, `generate.sh`, `inline-stls.sh` keep working against
`src/gridfinity_base.scad` untouched. `export_plate` stays in the source (hidden-group
or Advanced — it can simply move to `[Hidden]` in the source too, since it's a
scripting hook, not a UI feature; `-D` overrides work on hidden variables).

### Verification

- Render each variant headless: single-plate manual case, multi-plate cover case,
  dev both — assert manifold + expected footprint (reuse the existing test approach).
- Diff check: variant body must be byte-identical to source body (only headers differ).
- Customizer smoke test: open each variant in desktop OpenSCAD's Customizer and
  confirm section order and absence of pinned params.
- MakerWorld upload checklist (manual): multi variant generates N plates, empty plates
  discarded, no top-level bleed into plates; single variant still offers STL download.
- README: rewrite the "Publishing on MakerWorld" section for the two-listing setup.

### Open decisions

1. Product names for the two uploaded `.scad` files.
2. Multi-plate cover-size defaults (recommend non-zero, e.g. 400×400).
3. Whether cover sliders should have a non-zero minimum (e.g. 42) in the multi variant.
4. Whether to also emit the dev file into `build/` or leave `src/` as the dev artifact.

## Strategy B: STL-only, "Split to Objects" workflow

Drop MakerWorld multi-plate (PMM hook) support entirely. Every path — single plate
and multi-plate — exports **one STL**. The user workflow becomes:

1. Open one of our published, optimized print-profile 3MFs in Bambu Studio.
2. Import the downloaded STL.
3. Multi-plate only: click the object → **Split to Objects** → press **A**
   (auto-arrange). Three inputs total — far easier than exporting objects out of
   PMM's badly-profiled 3MF into a good one.

This keeps the user inside a correct print profile the whole time, which is the
actual problem being solved.

### The blocker: Split to Objects splits too much

Bambu's Split to Objects separates a mesh into its topologically connected
components. Plates were designed for this and split perfectly — except for small
box-shaped interior support structures inside the Beam/Beam+ corners, which break
out as dozens of tiny loose objects.

**Research findings (measured, 3×3 plate, `rigid` and `net_rigid`):**

- `rigid` and `net_rigid` plates: **21 shells** — 1 main body + 20 floating boxes.
  `net_light` / `net_heavy` plates: already **1 shell** (not affected). All 15 source
  STLs in `stl/` are single shells — the boxes emerge during CSG assembly.
- The floating boxes, all spanning **Z 0.6..3.25** (the bin-clearance relief-notch
  band of the Solid corner meshes):
  - **1.4 × 1.4 mm pillar** centered on every interior 4-cell crossing point
    (formed by the four meshes' 0.7×0.7 origin notches surrounding it);
  - **0.8 × 0.1 mm sliver** at every interior corner-arm tip (the wall material
    between an arm's own 0.4-wide tip notch and the mating arm's coincident face).
  - Count scales with interior intersections: a 3×3 plate has 4 crossings × (1
    pillar + 4 arm-tip slivers) = 20.
- **Key fact (established by signed-volume analysis):** the boxes are not solid
  pillars — they are **sealed internal air pockets** (their shells have negative
  signed volume). The four meshes' notches combine into enclosed cavities buried
  inside the double walls. They are intentional: the cavity splits the wide wall
  into separated perimeter lines when sliced. But a sealed cavity is *always* a
  separate closed shell in any exported mesh.

### Answers to the two proposed fixes

**"Rearrange the data so the slicer knows they belong to the object" — not possible
in STL.** STL is a bag of triangles with no object/part structure; Split to Objects
has exactly one input signal, mesh connectivity — and a sealed cavity's boundary can
never be connected to the outer boundary. Worse, today's split workflow silently
*deletes the inner structure*: after splitting, the plate object has lost its
cavities (they became the loose boxes), so the walls slice solid.

**"Zero-width connecting plane" — not producible and not reliable.** OpenSCAD's CSG
only emits solid manifolds (a zero-thickness wall can't survive a union), and a
post-processed degenerate wall makes the file non-manifold, inviting import repair
to delete or re-split it. (Solid-to-solid epsilon welds were also tried and are
useless here — there is nothing solid to weld the "boxes" to; they are air.)

### The fix (implemented): vent each cavity to the underside

A cavity stops being a separate shell the moment it connects to outside air. Each
pocket gets a hair-thin vent channel cut down through the 0.6mm floor to the bed
(`crossing_vents()` in `src/gridfinity_base.scad`, subtracted in `assembly()` for
`rigid`/`net_rigid` only):

- one 0.2 × 0.2 channel under the crossing pocket, one 0.1 × 0.2 channel under each
  arm-tip pocket, at every interior 4-cell crossing;
- far below one extrusion line width, so slicers drop them from toolpaths — the
  printed plate is unchanged — and they exit via the underside, invisible on the
  finished print;
- the cavities survive as (now open) pockets, preserving the separated-wall
  structure, and survive Split to Objects attached to their plate.

### Verification (done locally, pending Bambu Studio confirmation)

- Shell counts after venting: Beam and Beam+ 3×3 = **1 shell** (was 21); 2.5×2.5
  half-cells, 4×4 with Custom Shape cuts, 3×3 with spacers = 1 shell each;
  Net+/Tape+ unchanged at 1; auto layout 500×450/P1S = **6 shells for 6 plates**.
- Volume accounting is exact: 3×3 Beam = 7102.6 (outer) − 24.17 (cavities kept)
  − 0.29 (vent floor material) = 7078.1 mm³ measured.
- Test STLs for Bambu Studio in `build/split-test/`: import → Split to Objects →
  expect plates only, no loose boxes; slice and confirm vents don't appear in
  toolpaths and cavity walls still slice as separated perimeters.
- Worth adding `tools/check_shells.py` to encode the 1-shell-per-plate contract.

### Consequences for Strategy A if B is adopted

- `src/makerworld_hooks.scad`, `make_makerworld.sh`, `mw_export`, and
  `mw_safe_plates` are all deleted rather than restructured.
- The two MakerWorld customizers from Strategy A remain a good idea (the parameter
  simplification stands on its own), but the multi-plate variant becomes a plain
  STL-download listing whose output is the gapped auto layout — no PMM hooks, no
  3MF path, no 235 mm arranger cap (that cap existed only for PMM's arranger).
- README's publishing section documents the 3-click workflow (import → split →
  arrange) alongside the published print-profile 3MFs.

## Recommendation

The strategies compose rather than compete: B fixes the export/profile problem, A
fixes the customizer UX. Suggested order: implement the weld plugs first (small,
self-contained, testable locally), verify Split to Objects behaves in Bambu Studio,
then do the A restructure with B's simplifications (no hooks/mw_export machinery at
all), which makes the build tool even thinner.

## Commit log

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2026-06-12 Organize repo, add README, and add Net Rigid variant
    - Move SCAD source into src/ and all STLs into stl/; fix import() paths
    - Add README: variants, benchmarks vs competitors, install + customization
    - Add fourth variant "Net Rigid" (Tape↔Rigid blend) with its own corner
    and connector (12mm corner, 0.9 x 3.5 connector)
    - Add gitignored build/ folder for STL exports
    [AT Net Heavy Connector.stl, AT Net Heavy Corner.stl, AT Net Light Connector.stl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]
2026-06-12 Add drawer spacers, fractional grid sizes, and total-size readout
    - Drawer Spacers: per-side outward extensions (front/back/left/right,
    0-41mm) built from the new AT Extension.stl, doubled ridge-to-ridge at
    interior corners and single at the ends.
    - Grid columns/rows are now 0.5-step sliders (1-20.5); a .5 adds a
    half-cell column/row, replacing the half-cell checkboxes.
    - Echo the total outer footprint (incl. spacers) to the Console.
    [AT Extension.stl, gridfinity_base.scad]
2026-06-13 Add tie-rail along spacer outer edges for rigidity
    When an edge has drawer spacers, run a beam along the far (outer) edge
    welding all the spacer tips together so the cantilevered prisms can't
    splay. Always uses the Net Heavy connector profile (2.15 x 0.5),
    regardless of model, and is inset so the drawer footprint is unchanged.
    [AT Net Heavy Beam Connector.stl, gridfinity_base.scad]
2026-06-14 Inline geometry so the model is self-contained for MakerWorld
    Replace the import() of ../stl/*.stl corner/extension/beam meshes with
    inlined polyhedron() modules, so src/gridfinity_base.scad runs in
    MakerWorld's Parametric Model Maker with no external dependencies.
    Geometry is byte-identical to the imported meshes (same volume/bbox;
    welded vertices yield a slightly cleaner tessellation). Also document
    the Net Beam variant in the README.
    [AT Net Heavy Beam Connector.stl, gridfinity_base.scad]
2026-06-14 Fix inverted normals on MakerWorld, add centered option, hide constants
    - Reverse the inlined polyhedron face winding (STL is CCW-from-outside,
    OpenSCAD polyhedron() wants CW). import()+CGAL masked this locally, but
    MakerWorld's Manifold backend honored the winding and rendered the
    corners/beam/extension inside-out. Solids are geometrically unchanged.
    - Add a "centered" Advanced checkbox (default on) that centers the X/Y
    footprint — including asymmetric drawer spacers — on the origin, Z left
    on the bed.
    - Add a [Hidden] group so internal constants (beam_len, ext_base_len,
    rail_*) no longer show as Customizer parameters.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
    [gridfinity_base.scad]
2026-06-14 Add Solid+ corner selection, STL inliner tool, and preview color
    - Solid+ (net_rigid): inner corners + connectors are plain Solid (rigid);
    the Solid+ corner is used only on outer-perimeter edges that have no
    drawer spacer. An outer plate corner with a spacer in either direction
    falls back to the Solid corner. Pulls in the updated 4.0mm Net Rigid
    Corner STL (now height-matched to Solid).
    - tools/inline_stls.py: regenerates the inlined polyhedron() meshes from
    the STLs named in each module's "// source-stl:" directive. Reverses
    STL winding (CCW-from-outside) to what polyhedron() wants (CW), so
    normals render outward on MakerWorld's Manifold backend; idempotent.
    - preview_color: u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
    [AT Net Rigid Connector.stl, AT Net Rigid Corner.stl, gridfinity_base.scad]
2026-06-15 Lower mesh top surfaces to 3.0mm and re-inline
    Re-exported the corner, beam, and extension STLs with their top faces
    dropped from 3.5mm to 3.0mm, then regenerated the inlined polyhedron()
    blocks via ./inline-stls.sh.
    [AT Extension.stl, AT Net Heavy Beam Connector.stl, AT Net Heavy Connector.stl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]
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2026-07-05 Add Custom Shape: per-row left/right square cuts for non-rectangular plates
    - 20 new Customizer params (cut_left_1..10 / cut_right_1..10, row 1 = front)
    - Grid is now a per-cell presence model: each cell classifies its sides by
    neighbour presence, so jagged steps get correct outer / inner-outer / Solid+
    corners automatically
    - Spacers rebuilt per present edge cell: front/back run only along surviving
    first/last-row squares, left/right only along rows with a zero cut on that side
    - Plug the 0.7mm inner-corner relief notch at re-entrant corners (Solid/Solid+)
    to avoid a non-manifold wall pinch where the diagonal cell was cut away
    - Console notes for clamped cuts, ignored rows, and disc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
    [gridfinity_base.scad]
2026-07-05 Solid+: use connectable outer corner at open intersections
    For net_rigid, any intersection with a missing square must present the
    connectable outer profile on every square-corner around it — the edge-connector
    clip only fits against outer corners. The diagonal cell at a re-entrant corner
    previously kept the fully-interior corner; it now swaps in the Solid+ outer
    mesh (corner_part gains an 'open' flag). Plain Solid intentionally keeps the
    interior corner there, so the notch plug is now gated to model==rigid only.
    [gridfinity_base.scad]
2026-07-05 Rebrand as Filament Zero: Net+/Tape+/Beam/Beam+ naming, MIT license
    README now leads with the project's actual goal - the absolute minimum
    filament and print time that still makes a usable Gridfinity base - and
    describes the three structure levels plus the connector story behind the
    '+' variants. Sync generate.sh labels to the customizer names (dropping
    net_beam, which is no longer exposed in the customizer). Add MIT LICENSE.
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2026-07-11 feat: Auto Baseplates - cover an area with auto-chunked, printer-sized plates
    Set cover_width x cover_depth (both non-zero) and the solver fits the largest
    half-pitch grid inside the area, turns the leftover mm into edge spacers
    (split left/right; depth remainder to the back), and chunks the grid into
    plates that each fit the selected printer (Bambu lineup dropdown + custom).
    Plates render in assembled positions with a small gap so the slicer can
    split them into separate objects. Both cover sizes default to 0, so the
    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
    [gridfinity_base.scad]
2026-07-11 fix: use real single-color printable rectangles, not advertised bed sizes
    Sourced from Bambu Studio's official machine profiles (bed_exclude_area /
    extruder_printable_area): P1P/P1S/X1C/X1E lose an 18x28mm front-left corner
    to the filament-cutter stopper, so their largest full-depth rectangle is
    238x256; the dual-nozzle H2D/H2D Pro (350x320 bed) and H2C (330x320 bed)
    print a single color from one nozzle that only reaches 325mm; A1/A1 mini/
    P2S/X2D/H2S have no exclusions. Also adds the missing A2L (330x320),
    H2D Pro and H2C to the printer dropdown.
    [gridfinity_base.scad]
2026-07-11 feat: per-plate export - MakerWorld multi-plate 3MF hooks + local STL batching
    Exporting the auto layout as one STL forced slicers to Split to Objects,
    which explodes the plates' intentionally disconnected lattice into hundreds
    of bodies. Plates now export as genuinely separate objects, two ways:
    - MakerWorld: mw_plate_1..36 + mw_assembly_view modules per the official PMM
    multi-plate convention (one module per build plate, empty plates discarded,
    assembly view is preview-only). ./make_makerworld.sh generates the upload
    variant by flipping the hidden mw_export switch, which silences the top-
    level render so the plate modules are the only output. MakerWorld drops
    STL download for mu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
    [gridfinity_base.scad]
2026-07-11 fix: MakerWorld exported N copies of the whole layout - keep hooks out of src
    PMM renders the script's top level into every mw_plate_N() module it finds,
    so the src file (top-level render active) produced 36 plates each containing
    the entire assembled layout (diagnosed from the generated 3MF: all 36 objects
    spanned the full 223.5x334mm cover). The hooks now live only in
    src/makerworld_hooks.scad, appended by make_makerworld.sh after silencing the
    top level - and the script refuses to build if hooks ever leak into src.
    Uploading the plain src file to MakerWorld now just behaves as a normal
    single-output customizer script (STL button intact).
    Also: cover_width/cover_depth sliders now step in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
    [gridfinity_base.scad, makerworld_hooks.scad]
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2026-07-11 fix: position MakerWorld plates on the bed - PMM auto-arrange can't hold them
    PMM's auto-arranger tops out around 240x235mm; bigger auto-sized plates make
    it fail ("Model cannot fit in plates, disable auto-arrangement") and the
    download degrades to one fused object. With auto-arrangement disabled, the
    geometry's own coordinates become the placement, so the mw_plate hooks now
    translate each plate to the center of the selected printer's usable
    rectangle - the bed table gained per-printer printable-origin offsets so
    P1/X1 plates sit right of the 18x28 cutter corner (e.g. x 25..249 for a
    224mm plate on a 256 bed).
    [gridfinity_base.scad, makerworld_hooks.scad]
2026-07-11 fix: cap MakerWorld plates at 235mm so auto-arrangement always succeeds
    The profile's Auto Arrangement toggle is easy to miss and easy to not-save,
    and while it's on, any plate over ~240mm makes PMM degrade the download to
    one fused assembly-view object. The MakerWorld variant now caps plate size
    at 235mm by default (new mw_safe_plates checkbox, MakerWorld-build only -
    desktop and export_plates.sh stay uncapped), so the multi-plate 3MF works
    without touching profile settings. Unchecking it restores full-bed plates
    for profiles with Auto Arrangement disabled. 224x329 on P1S still solves
    to 2 plates (224x210 + 224x119), both arranger-friendly.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
    [gridfinity_base.scad]
2026-07-12 feat: two-piece V2 drawer-spacer extensions + Beam+ corner rule + spacer_* rename
    - Extensions split into two meshes: the Extender (beam-connector L-profile,
    stretched the full distance) and a 1mm End cap with the old solid taper at
    the tip. Less filament, and extensions now mate with the interlock system.
    Caps only appear on extensions 5mm and longer.
    - Beam+ keeps its connector (plus) corner whenever any boundary edge at the
    corner is exposed; only a corner spacered in every boundary direction falls
    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
    [AT Extension V2 End.stl, AT Extension V2 Extender.stl, gridfinity_base.scad]
2026-07-12 fix: vent sealed notch cavities so Split to Objects keeps plates whole
    The Solid corners' relief notches combine into sealed air pockets at every
    interior 4-cell crossing (one 1.4x1.4 on the crossing, one 0.1x0.8 at each
    arm tip). Sealed cavities are always separate shells in the exported mesh,
    so slicers' "Split to Objects" broke them out as loose boxes - and quietly
    deleted the inner wall structure from the plate.
    Cut a hair-thin vent channel from each pocket down through the 0.6mm floor:
    the cavity joins the outer boundary (one connected shell per plate) and
    survives splitting. The channels are far below one extrusion width, so
    toolpaths are unchanged. Beam/Beam+ 3x3 now exports 1 shell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
    [gridfinity_base.scad]
2026-07-12 docs: plan for split customizers + STL-only workflow
    Strategy A: single-plate and multi-plate MakerWorld customizers built from
    the one combined source. Strategy B: drop PMM multi-plate 3MF support, use
    STL + Split to Objects + auto-arrange (unblocked by the cavity vent fix).
2026-07-12 feat: two MakerWorld customizers (Single-Plate / Baseplate Set), drop PMM multi-plate
    MakerWorld now gets two purpose-built single-output scripts generated by
    tools/build_variants.py (./make_makerworld.sh):
    - Single-Plate: Model, Grid, Drawer Spacers, Custom Shape, Advanced; the
    Auto Baseplates solver is pinned off.
    - Multi-Plate Baseplate Set: Model, then Auto Baseplate Set Generation
    (printer first, then cover area; ships at 400x400), then Advanced; the
    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
    [gridfinity_base.scad, makerworld_hooks.scad]
2026-07-12 tweak: move Custom printer size to Advanced
    custom_print_width/depth are rarely used - they now live under Advanced
    (pinned off in the Single-Plate variant like tile_gap), and the printer
    picker's Custom entry says "set size under Advanced".
    [gridfinity_base.scad]
2026-07-12 feat: drawer_spacers and half_tiles toggles for Auto Baseplates
    Two checkboxes in the Auto Baseplate Set Generation section (so they appear
    in the Multi-Plate customizer; the Single-Plate variant pins them):
    - drawer_spacers (default on): uncheck for bare plates - the slack is not
    filled and the assembled footprint shrinks to the largest grid that fits.
    - half_tiles (default on): uncheck to use whole 42mm squares only; the
    larger leftover flows into the drawer spacers so the footprint still
    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
    [gridfinity_base.scad]
2026-07-12 feat: sparse plates - merge cells up to 2x2 and delete internal walls
    New `sparse` customizer boolean (default off) in the [Model] section, so it
    appears in both the Single and Multi Baseplate customizers; the multi-plate
    layout logic is untouched - each tile is independently sparse inside its own
    full perimeter.
    Deterministic front-left merge of full-size cells: 2x2 quads first, then a
    leftover column pairs into 1x2s and a leftover row into 2x1s (odd x odd
    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
    [gridfinity_base.scad]
2026-07-12 feat: commit generated customizer variants under build-src/
    The two MakerWorld .scad outputs now land in build-src/ (committed) instead
    of the git-ignored build/, so the exact shipped files exist in the repo even
    without rerunning the generator.
    [3DMM Filament Zero Gridfinity Multi Baseplate.scad, 3DMM Filament Zero Gridfinity Single Baseplate.scad]
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2026-07-12 feat: width/depth alignment picklists replace the drawer-spacers boolean
    The Multi Baseplate's fill control is now two picklists: Width alignment
    (left / center / right / none, default center) and Depth alignment
    (front / center / back / none, default front). The grid hugs the chosen
    side and the drawer spacers fill the opposite side(s) - left-aligned grids
    get right spacers, centered splits evenly, "none" drops the spacers so the
    footprint shrinks to the bare grid on that axis.
    Defaults (center/front) reproduce the old behavior exactly (verified
    canonically identical). Plate splitting, per-plate spec assignment,
    centering, and console echoes all honor the per-side amounts - a
    back-aligned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
    [3DMM Filament Zero Gridfinity Multi Baseplate.scad, 3DMM Filament Zero Gridfinity Single Baseplate.scad, gridfinity_base.scad]
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
